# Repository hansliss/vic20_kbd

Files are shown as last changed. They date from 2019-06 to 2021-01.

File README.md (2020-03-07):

# vic20_kbd
A Cherry MX based keyboard for the VIC-20/C64, using the same matrix/interface, and aiming for the same form factor.

SHIFT LOCK is implemented with a flip-flop instead of a toggling switch.

The anti-ghosting diodes are probably not really needed, I just thought it SHOULD have them. Have fun soldering!

I use a normal 2.54mm pitch single-row pin header socket for the keyboard connector, with the cables soldered on, secured with shrink tubing and hot glue. This seems sturdy enough. Plug pin #2, the key pin, with something.

Print the stem adapters from CBMKeyAdapter.scad on an FDM printer using a .25mm nozzle. A resin printer produces better results, but the material is typically much too brittle for this kind of thing.

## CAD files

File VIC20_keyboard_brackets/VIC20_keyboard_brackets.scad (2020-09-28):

$fn=256;

holeYDistance=114;
outerHoleXDistance=317;
innerHoleTopXDistance=102;
innerHoleBotXDistance=63.5;
shellScrewHoleDia=3;
shellScrewHeadDia=6;
shellScrewHoleBottomDia=5;
outerHoleXDistanceFromShell=40;
liftHeight=10;
mountHoleDistXRight=32;
mountHoleDistXLeft=11;
mountHoleYDist=92;
pcbYDistance=100;

translate([0, holeYDistance/2, liftHeight])
    difference() {
        translate([0, 0, 2/2])
            cube([10, 15, 2], center=true);
        translate([0, 0, -0.01])
            cylinder(r=shellScrewHoleBottomDia/2, h=1.5);
        translate([0, 0, -0.01])
            cylinder(r=shellScrewHoleDia/2, h=3);
    }
    
translate([0, -holeYDistance/2, liftHeight])
    difference() {
        translate([0, 0, 2/2])
            cube([10, 15, 2], center=true);
        translate([0, 0, -0.01])
            cylinder(r=shellScrewHoleBottomDia/2, h=1.5);
        translate([0, 0, -0.01])
            cylinder(r=shellScrewHoleDia/2, h=3);
    }

difference() {
    translate([10, 0, 2/2])
        cube([outerHoleXDistanceFromShell + 20, pcbYDistance, 2], center=true);
    translate([mountHoleDistXRight, mountHoleYDist/2, -0.01])
        cylinder(r=1.5, h=3);
    translate([mountHoleDistXRight, -mountHoleYDist/2, -0.01])
        cylinder(r=1.5, h=3);
    translate([mountHoleDistXLeft, mountHoleYDist/2, -0.01])
        cylinder(r=1.5, h=3);
    translate([mountHoleDistXLeft, -mountHoleYDist/2, -0.01])
        cylinder(r=1.5, h=3);
}

translate([0, -pcbYDistance/2+1, 2-0.5])
    rotate([10, 0, 0])
        translate([0, 0, liftHeight/2])
            cube([10, 2, liftHeight], center=true);

translate([0, pcbYDistance/2-1, 2-0.5])
    rotate([-10, 0, 0])
        translate([0, 0, liftHeight/2])
            cube([10, 2, liftHeight], center=true);

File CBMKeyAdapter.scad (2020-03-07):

/*
Key stem adapters for fitting VIC-20/C64 keycaps on Cherry MX keyswitches.
This will produce a complete set of adapters for a VIC-20 keyboard, including
double-stem ones for the 1 1/2U keys (function keys, CTRL, SHIFT, RESTORE).

The basic templates for the two stem types are supposed to be accurate in scale,
with scale factors added to provide add some space for actually fitting the
resulting adapters. You may need to experiment with the scale factors, depending
on your material's shrinkage factor. I developed this for ABS.

Print using a .25 nozzle, and *lift* the models a couple of mm above the buildplate,
to get supports added underneath! Make sure your slicer doesn't drop them straight
back down on the buildplate - there should be a setting for this.
*/

$fn=256;
cherrywidth=4;
cherrythickness=1.1;
cherryheight=3.5;
cherrybasewidth=7.2;
cherrybasedepth=5.5;
cherryTopThickness=1;
cbmwidth=4.6;
cbmthickness=1.4;
cbmheight=5;
cbmStemDist=9.4;
cbmPlateWidth=7;
cbmScaleFactor=0.999;
cherryScaleFactor=1.009;

module cherryStem() {
    union() {
        cube([cherrywidth, cherrythickness, cherryheight+1], center=true);
        cube([cherrythickness, cherrywidth, cherryheight+1], center=true);
    }
}

module cbmStem() {
    union() {
        cube([cbmwidth, cbmthickness, cbmheight], center=true);
        cube([cbmthickness, cbmwidth, cbmheight], center=true);
    }
}

module singleStem() {
    union() {
        difference() {
            cylinder(r=cherrybasedepth/2-0.1, h=cherryheight + cherryTopThickness);
            scale([cherryScaleFactor, cherryScaleFactor, 1])
                translate([0, 0, cherryheight/2-0.01])
                    cherryStem();
        }
        scale([cbmScaleFactor, cbmScaleFactor, cbmScaleFactor])
            translate([0, 0, cherryheight + 1 + cbmheight/2 - 0.01])
                cbmStem();
    }
}

module oneOneHalfStem() {
    union() {
        difference() {
            cylinder(r=cherrybasedepth/2-0.1, h=cherryheight + cherryTopThickness);
            scale([cherryScaleFactor, cherryScaleFactor, 1])
                translate([0, 0, cherryheight/2-0.01])
                    cherryStem();
        }
        translate([0, 0, cherryheight + cherryTopThickness/2])
            //minkowski() {
                cube([cbmStemDist + 2 * cbmwidth/2+2, cbmPlateWidth, cherryTopThickness + 0.02], center=true);
              //  sphere(0.5);
            //}
        translate([-cbmStemDist/2, 0, 0])
            scale([cbmScaleFactor, cbmScaleFactor, cbmScaleFactor])
                translate([0, 0, cherryheight + 1 + cbmheight/2 - 0.01])
                    cbmStem();
        translate([cbmStemDist/2, 0, 0])
            scale([cbmScaleFactor, cbmScaleFactor, cbmScaleFactor])
                translate([0, 0, cherryheight + 1 + cbmheight/2 - 0.01])
                    cbmStem();
    }
}

for (i = [0 : 63]) {
    x = (cherrybasedepth + 2) * (i % 8);
    y = (cherrybasedepth + 2) * floor(i / 8);
    translate([x, y, 2])
        singleStem();
}

for (i = [0 : 8]) {
    x = 2 * (cherrybasedepth + 4) * (i % 3) + cherrybasedepth + 2;
    y = (cherrybasedepth + 3) * (floor(i / 3)) + (cherrybasedepth + 2) * 8;
        translate([x, y, 2])
        oneOneHalfStem();
}

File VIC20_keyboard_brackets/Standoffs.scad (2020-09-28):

$fn=256;

module standoff() {
    difference() {
        cylinder(r=2.5, h=1.5);
        translate([0, 0, -0.01])
            cylinder(r=1.8, h=1.52);
    }
}


for (x = [0:5]) {
    for (y = [0:5]) {
        translate([x * 6, y * 6, 0])
            standoff();
    }
}

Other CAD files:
VIC20_keyboard_brackets/VIC20_keyboard_brackets_center.scad

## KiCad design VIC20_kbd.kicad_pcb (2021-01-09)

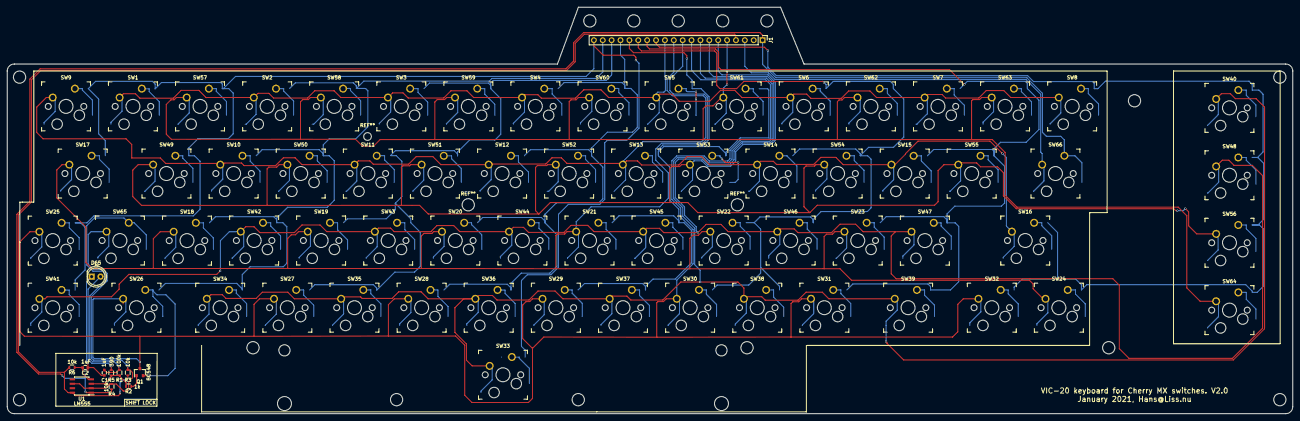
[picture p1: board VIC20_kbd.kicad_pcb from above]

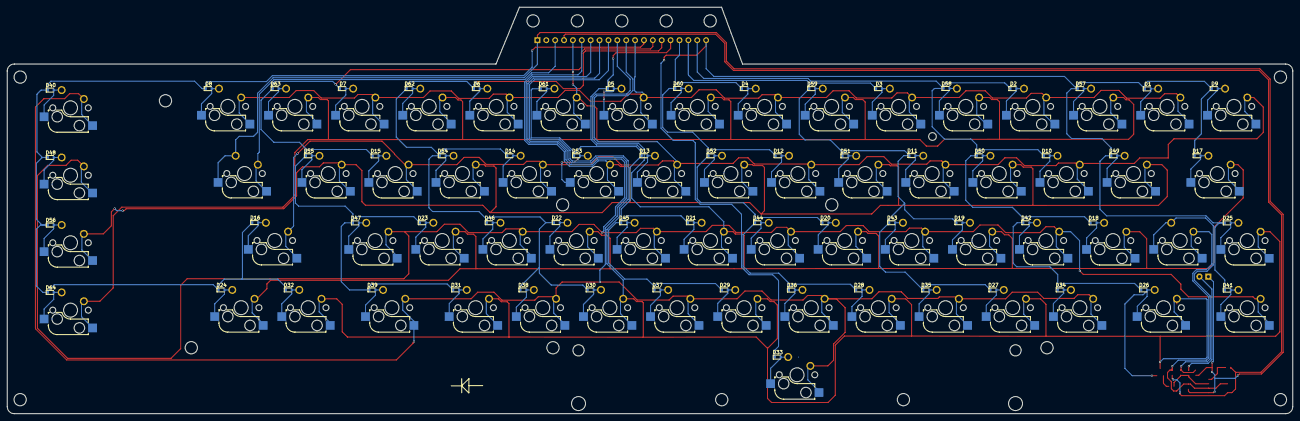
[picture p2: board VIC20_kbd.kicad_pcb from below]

Board: 2 copper layers, 367.7 x 116.2 mm, 142 parts (64 on the bottom side), 89 nets.

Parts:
C1, C2: 1uF; C_0603
D1, D2, D3, D4, D5, D6, D7, D8, D9, D10, D11, D12, D13, D14, D15, D16, D17, D18, D19, D20, D21, D22, D23, D24, D25, D26, D27, D28, D29, D30, D31, D32, D33, D34, D35, D36, D37, D38, D39, D40, D41, D42, D43, D44, D45, D46, D47, D48, D49, D50, D51, D52, D53, D54, D55, D56, D57, D58, D59, D60, D61, D62, D63, D64: D; D_0603
D65: LED; LED_D5.0mm
J1: Conn_01x20; Pin_Header_Straight_1x20_Pitch2.54mm
Q1: BC548; SOT-23
R1: 100k; R_0603
R2: 1k; R_0603
R3, R4, R6: 10k; R_0603
R5: 390; R_0603
SW1: Key_1; Kailh_socket_MX_optional_compatible
SW2: Key_3; Kailh_socket_MX_optional_compatible
SW3: Key_5; Kailh_socket_MX_optional_compatible
SW4: Key_7; Kailh_socket_MX_optional_compatible
SW5: Key_9; Kailh_socket_MX_optional_compatible
SW6: Key_Plus; Kailh_socket_MX_optional_compatible
SW7: Key_Pound; Kailh_socket_MX_optional_compatible
SW8: Key_DEL; Kailh_socket_MX_optional_compatible
SW9: Key_ARROWLEFT; Kailh_socket_MX_optional_compatible
SW10: Key_W; Kailh_socket_MX_optional_compatible
SW11: Key_R; Kailh_socket_MX_optional_compatible
SW12: Key_Y; Kailh_socket_MX_optional_compatible
SW13: Key_I; Kailh_socket_MX_optional_compatible
SW14: Key_P; Kailh_socket_MX_optional_compatible
SW15: Key_asterisk; Kailh_socket_MX_optional_compatible
SW16: Key_RETURN; Kailh_socket_MX_optional_compatible
SW17: Key_CTRL; Kailh_socket_MX_optional_compatible
SW18: Key_A; Kailh_socket_MX_optional_compatible
SW19: Key_D; Kailh_socket_MX_optional_compatible
SW20: Key_G; Kailh_socket_MX_optional_compatible
SW21: Key_J; Kailh_socket_MX_optional_compatible
SW22: Key_L; Kailh_socket_MX_optional_compatible
SW23: Key_semicolon; Kailh_socket_MX_optional_compatible
SW24: Key_CRSRRIGHT; Kailh_socket_MX_optional_compatible
SW25: Key_STOP; Kailh_socket_MX_optional_compatible
SW26: Key_LSHFT; Kailh_socket_MX_optional_compatible
SW27: Key_X; Kailh_socket_MX_optional_compatible
SW28: Key_V; Kailh_socket_MX_optional_compatible
SW29: Key_N; Kailh_socket_MX_optional_compatible
SW30: Key_comma; Kailh_socket_MX_optional_compatible
SW31: Key_slash; Kailh_socket_MX_optional_compatible
SW32: Key_CRSRDOWN; Kailh_socket_MX_optional_compatible
SW33: Key_SPACE; Kailh_socket_MX_optional_compatible
SW34: Key_Z; Kailh_socket_MX_optional_compatible
SW35: Key_C; Kailh_socket_MX_optional_compatible
SW36: Key_B; Kailh_socket_MX_optional_compatible
SW37: Key_M; Kailh_socket_MX_optional_compatible
SW38: Key_period; Kailh_socket_MX_optional_compatible
SW39: Key_RSHFT; Kailh_socket_MX_optional_compatible
SW40: Key_F1; Kailh_socket_MX_optional_compatible
SW41: Key_CBM; Kailh_socket_MX_optional_compatible
SW42: Key_S; Kailh_socket_MX_optional_compatible
SW43: Key_F; Kailh_socket_MX_optional_compatible
SW44: Key_H; Kailh_socket_MX_optional_compatible
SW45: Key_K; Kailh_socket_MX_optional_compatible
SW46: Key_colon; Kailh_socket_MX_optional_compatible
SW47: Key_equals; Kailh_socket_MX_optional_compatible
SW48: Key_F3; Kailh_socket_MX_optional_compatible
SW49: Key_Q; Kailh_socket_MX_optional_compatible
SW50: Key_E; Kailh_socket_MX_optional_compatible
SW51: Key_T; Kailh_socket_MX_optional_compatible
SW52: Key_U; Kailh_socket_MX_optional_compatible
SW53: Key_O; Kailh_socket_MX_optional_compatible
SW54: Key_at; Kailh_socket_MX_optional_compatible
SW55: Key_ARROWUP; Kailh_socket_MX_optional_compatible
SW56: Key_F5; Kailh_socket_MX_optional_compatible
SW57: Key_2; Kailh_socket_MX_optional_compatible
SW58: Key_4; Kailh_socket_MX_optional_compatible
SW59: Key_6; Kailh_socket_MX_optional_compatible
SW60: Key_8; Kailh_socket_MX_optional_compatible
SW61: Key_0; Kailh_socket_MX_optional_compatible
SW62: Key_minus; Kailh_socket_MX_optional_compatible
SW63: Key_HOME; Kailh_socket_MX_optional_compatible
SW64: Key_F7; Kailh_socket_MX_optional_compatible
SW65: Key_SHFTLCK; Kailh_socket_MX_optional_compatible
SW66: Key_RESTORE; Kailh_socket_MX_optional_compatible
U1: LM555; SOIC-8_3.9x4.9mm_Pitch1.27mm

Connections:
/C0: J1.12, SW1.2, SW2.2, SW3.2, SW4.2, SW5.2, SW6.2, SW7.2, SW8.2
/C1: J1.11, SW9.2, SW10.2, SW11.2, SW12.2, SW13.2, SW14.2, SW15.2, SW16.2
/C2: J1.10, SW17.2, SW18.2, SW19.2, SW20.2, SW21.2, SW22.2, SW23.2, SW24.2
/C3: J1.9, Q1.3, SW25.2, SW26.2, SW27.2, SW28.2, SW29.2, SW30.2, SW31.2, SW32.2
/C4: J1.8, SW33.2, SW34.2, SW35.2, SW36.2, SW37.2, SW38.2, SW39.2, SW40.2
/C5: J1.7, SW41.2, SW42.2, SW43.2, SW44.2, SW45.2, SW46.2, SW47.2, SW48.2
/C6: J1.6, SW49.2, SW50.2, SW51.2, SW52.2, SW53.2, SW54.2, SW55.2, SW56.2
/C7: J1.5, SW57.2, SW58.2, SW59.2, SW60.2, SW61.2, SW62.2, SW63.2, SW64.2
/R8: J1.3, SW66.2
/RA: D1.1, D9.1, D17.1, D25.1, D33.1, D41.1, D49.1, D57.1, J1.20
/RB: D2.1, D10.1, D18.1, D26.1, D34.1, D42.1, D50.1, D58.1, J1.19
/RC: D3.1, D11.1, D19.1, D27.1, D35.1, D43.1, D51.1, D59.1, J1.18
/RD: D4.1, D12.1, D20.1, D28.1, D36.1, D44.1, D52.1, D60.1, J1.17
/RE: D5.1, D13.1, D21.1, D29.1, D37.1, D45.1, D53.1, D61.1, J1.16
/RF: D6.1, D14.1, D22.1, D30.1, D38.1, D46.1, D54.1, D62.1, J1.15
/RG: D7.1, D15.1, D23.1, D31.1, D39.1, D47.1, D55.1, D63.1, J1.14
/RH: D8.1, D16.1, D24.1, D32.1, D40.1, D48.1, D56.1, D64.1, J1.13
GND: C1.2, C2.2, D65.1, J1.1, R4.2, SW66.1, U1.1
unnamed: C1.1, R1.2, SW65.1
unnamed: C2.1, R6.2, U1.4
unnamed: D1.2, SW1.1
unnamed: D2.2, SW2.1
unnamed: D3.2, SW3.1
unnamed: D4.2, SW4.1
unnamed: D5.2, SW5.1
unnamed: D6.2, SW6.1
unnamed: D7.2, SW7.1
unnamed: D8.2, SW8.1
unnamed: D9.2, SW9.1
unnamed: D10.2, SW10.1
unnamed: D11.2, SW11.1
unnamed: D12.2, SW12.1
unnamed: D13.2, SW13.1
unnamed: D14.2, SW14.1
unnamed: D15.2, SW15.1
unnamed: D16.2, SW16.1
unnamed: D17.2, SW17.1
unnamed: D18.2, SW18.1
unnamed: D19.2, SW19.1
unnamed: D20.2, SW20.1
unnamed: D21.2, SW21.1
unnamed: D22.2, SW22.1
unnamed: D23.2, SW23.1
unnamed: D24.2, SW24.1
unnamed: D25.2, SW25.1
unnamed: D26.2, Q1.2, SW26.1
unnamed: D27.2, SW27.1
unnamed: D28.2, SW28.1
unnamed: D29.2, SW29.1
unnamed: D30.2, SW30.1
unnamed: D31.2, SW31.1
unnamed: D32.2, SW32.1
unnamed: D33.2, SW33.1
unnamed: D34.2, SW34.1
unnamed: D35.2, SW35.1
unnamed: D36.2, SW36.1
unnamed: D37.2, SW37.1
unnamed: D38.2, SW38.1
unnamed: D39.2, SW39.1
unnamed: D40.2, SW40.1
unnamed: D41.2, SW41.1
unnamed: D42.2, SW42.1
unnamed: D43.2, SW43.1
unnamed: D44.2, SW44.1
unnamed: D45.2, SW45.1
unnamed: D46.2, SW46.1
unnamed: D47.2, SW47.1
unnamed: D48.2, SW48.1
unnamed: D49.2, SW49.1
unnamed: D50.2, SW50.1
unnamed: D51.2, SW51.1
unnamed: D52.2, SW52.1
unnamed: D53.2, SW53.1
unnamed: D54.2, SW54.1
unnamed: D55.2, SW55.1
unnamed: D56.2, SW56.1
unnamed: D57.2, SW57.1
unnamed: D58.2, SW58.1
unnamed: D59.2, SW59.1
unnamed: D60.2, SW60.1
unnamed: D61.2, SW61.1
unnamed: D62.2, SW62.1
unnamed: D63.2, SW63.1
unnamed: D64.2, SW64.1
unnamed: D65.2, R5.2
unnamed: Q1.1, R2.1
unnamed: R1.1, R2.2, R5.1, U1.3
unnamed: R3.1, R4.1, SW65.2, U1.2, U1.6
VCC: J1.4, R3.2, R6.1, U1.8

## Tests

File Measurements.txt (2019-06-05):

Main opening
-10.6, 55.26 - 296.4, 55.26
296.4, 55.26 - 296.4, 95.76
296.4, 95.76, 291.4, 95.76
291.4, 95.76 - 291.4, 133.76
291.4, 133.76 - 210.4, 133.76
210.4, 133.76 - 210.4 - 152.76
210.4, 152.76 - 37.4, 152.76
37.4, 152.76 - 37.4, 133.76
37.4, 133.76 - -14.6, 133.76
-14.6, 133.76 - -14.6, 92.76
-14.6, 92.76 - -10.6, 92.76
-10.6, 92.76 - -10.6, 55.26

F-Key opening
315.4, 55.26 - 345.9, 55.26
345.9, 55.26 - 345.9, 133.26
345.9, 133.26 - 315.4, 133.26
315.4, 133.26 - 315.4 - 55.26

Mounting holes
17.4, 46.26
124.9, 46.26
226.4, 46.26
334.4, 46.26
17.4, 159.76
144.4, 159.76
208.4, 159.76
334.4, 159.76

MX1A-11NW
MX1A-E1NW

MX1A-31NW

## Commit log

2019-06-05 Initial import
    [VIC20_kbd.kicad_pcb, VIC20_kbd.sch]
2019-06-06 Added rounded corners Added mounting holes and cables support holes
    [VIC20_kbd.kicad_pcb]
2019-06-09 Rerouted everything, tidier V1.2
    [VIC20_kbd.kicad_pcb]
2020-03-06 Added SHIFT LOCK flip-flop to PCB Added Gerber files
    [VIC20_kbd-B_Adhes.gbr, VIC20_kbd-B_CrtYd.gbr, VIC20_kbd-B_Cu.gbr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]
2020-03-07 Added key stem adapter source code.
    [CBMKeyAdapter.scad]
2020-09-28 Added simple mounting brackets in OpenSCAD format. Added sym-lib-table.
    [Standoffs.scad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]
2021-01-09 Cleaned up to accommodate Kailh sockets.
    [VIC20_kbd.kicad_pcb]
2021-01-09 Cleaned up SHIFT LOCK area and fixed silkscreen.
    [VIC20_kbd.kicad_pcb]
2021-01-09 Additional preparation for Kailh sockets
    [VIC20_kbd.kicad_pcb, VIC20_kbd.sch]
2021-01-09 Kailh sockets A big diode symbol on bottom silkscreen layer, as a guide.
    [VIC20_kbd-B_Adhes.gbr, VIC20_kbd-B_CrtYd.gbr, VIC20_kbd-B_Cu.gbr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]
